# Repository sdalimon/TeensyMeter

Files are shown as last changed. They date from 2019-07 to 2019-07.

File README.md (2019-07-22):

# TeensyMeter
A simple voltmeter using a Teensy 3.5/3.6

This was a PCB I made up to experiment with software RMS calculation.

The hardware provides the following:
  - Socket for a Teensy 3.5 or Teensy 3.6 processor board
  - Socket for a SparkFun 7 segment display module (I2C connection only)
  - 4 pushbuttons
  - Differential Amplifier connected to input A9 of the Teensy
  
The input is differential, but not isolated.  The input range is +/- 60 V.  No protection against overvoltage is provided except the series resistors.  Do not connect to hazardous voltages.

The software constantly displays either the average (DC, positive only) voltage or the calculated voltage.  SW1 selects DC and SW2 selects RMS.

Calibration of offset and gain is supported, but the results are pretty good with 0.1% resistors even without calibration.  The calibration constants are stored in the EEPROM and sane defaults are used if the EEPROM is corrupt.  
To calibrate:
  - Connect 0.00 V to the input (short the wires)
  - Press SW3
  - Connect 10.00 V DC to the input
  - Press SW4
  
The hardware was designed in KiCAD 5.1.2.  The deisgn includes both 2 layer and 4 layer layouts.  Only the 2 layer layout is tested.

The software was written using the Arduino SDK with the TeensyDuino add-on.  THe followinjg libraries are used:  Wire, EEPROM, CRC32.

Known issues:
 - The resistor footprints are too small.
 - The UART interface of the 7 segment display would be easier to use.
 - The software should make it harder to accidentally calibrate.

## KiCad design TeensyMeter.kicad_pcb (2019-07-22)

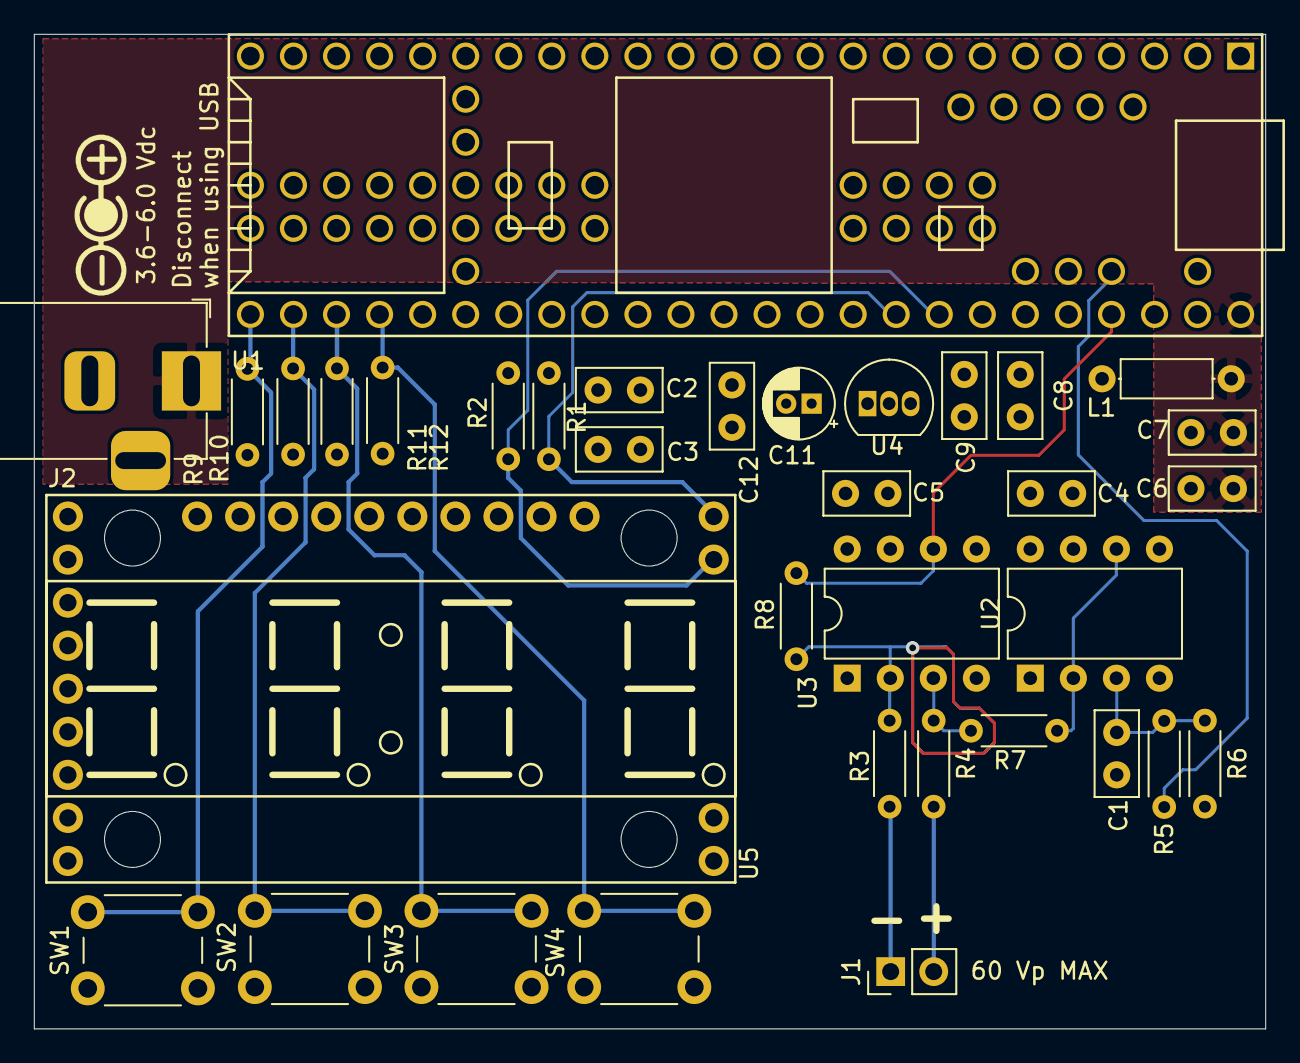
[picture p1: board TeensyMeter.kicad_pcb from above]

Board: 4 copper layers, 72.6 x 58.7 mm, 35 parts (0 on the bottom side), 20 nets.

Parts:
C1, C3, C4, C5, C7, C9, C12: 100n; C_Disc_D5.0mm_W2.5mm_P2.50mm
C2, C6, C8: 1u; C_Disc_D5.0mm_W2.5mm_P2.50mm
C11: 3u3; CP_Radial_D4.0mm_P1.50mm
J1: Conn_01x02; PinHeader_1x02_P2.54mm_Vertical
J2: Barrel_Jack; BarrelJack_Horizontal
L1: 600; L_Axial_L5.3mm_D2.2mm_P7.62mm_Horizontal_Vishay_IM-1
R1, R2, R5, R6, R9, R10, R11, R12: 10k; R_Axial_DIN0204_L3.6mm_D1.6mm_P5.08mm_Horizontal
R3, R4: 10MEG; R_Axial_DIN0204_L3.6mm_D1.6mm_P5.08mm_Horizontal
R7, R8: 221k; R_Axial_DIN0204_L3.6mm_D1.6mm_P5.08mm_Horizontal
SW1, SW2, SW3, SW4: SW_Push; SW_PUSH_6mm_H4.3mm
U1: Teensy3.6; Teensy35_36
U2, U3: MCP6281RT-E_OT DIP; DIP-8_W7.62mm
U4: LP2950-3.3_TO92; TO-92_Inline
U5: SparkFun_7seg

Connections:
+3.3VA: C4.1, C5.1, C11.1, C12.1, U2.7, U3.7, U4.1
+3V3: C2.1, C3.1, R1.1, R2.1, R9.1, R10.1, R11.1, R12.1, U1.15, U1.26, U1.51, U1.75, U5.6, U5.9, U5.10, U5.20
+5V: C6.1, C7.1, J2.1, L1.2, U1.53
+5VA: C8.1, C9.1, L1.1, U4.3
/A9: R8.1, U1.50, U3.6
/AREF: R5.1, U1.55
/INN: J1.1, R3.2
/INP: J1.2, R4.2
/MID: R7.2, U2.2, U2.6
/SCL: R2.2, U1.46, U5.12
/SDA: R1.2, U1.45, U5.13
GND: C2.2, C3.2, C6.2, C7.2, J2.2, SW1.1, SW2.1, SW3.1, SW4.1, U1.1, U1.27, U1.39, U1.61, U1.62, U1.74, U5.7, U5.8, U5.11, U5.21
GNDA: C1.2, C4.2, C5.2, C8.2, C9.2, C11.2, C12.2, R6.2, U1.52, U2.4, U3.4, U4.2
unnamed: C1.1, R5.2, R6.1, U2.3
unnamed: R3.1, R8.2, U3.2
unnamed: R4.1, R7.1, U3.3
unnamed: R9.2, SW1.2, U1.30
unnamed: R10.2, SW2.2, U1.31
unnamed: R11.2, SW3.2, U1.32
unnamed: R12.2, SW4.2, U1.33

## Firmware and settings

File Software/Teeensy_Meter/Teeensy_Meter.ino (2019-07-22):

#include <CRC32.h>

#include <Wire.h>
#include <EEPROM.h>

// Library Support Stuff
IntervalTimer t;   // Sampling timer

// Data Types
enum Mode {MODE_AVG, MODE_RMS, MODE_CAL};
struct CfgData {
  double gn;  // Calibrated Gain
  double ofs; // Calibrated Offset
  enum Mode mode; // Current Mode
  long crc;
};

// Strings
const char* STR_MODE_AVG = " DC "; // AVG with characters available on 7 seg display
const char* STR_MODE_RMS = "RMS "; // RMS with characters available on 7 seg display
const char* STR_MODE_CAL00 = "CL00"; // CAL 0.000 V - Prompt to apply 0 V for offset calibration
const char* STR_MODE_CAL10 = "CL10"; // CAL 10.00 V - Prompt to apply 10 V for gain calibration
const char CHR_7SEG_CLR = 0x76;  // Clear command for Sparkfun display
const char CHR_7SEG_DP = 0x77; // Followed by {X X AP CL D3 D2 D1 D0}

// Hardware configuration
const int led_pin = 13;
const int adc_in_pin = A9;               // ADC Input from amplifier
const int button_dc_pin = 33;              // Pushbuttons (0==Button pressed)
const int button_rms_pin = 34;
const int button_zero_pin = 35;
const int button_cal_pin = 36;
const int disp_i2c_addr = 0x71;          // SparkFun 7 seg ment display i2c address

// Parameters
const double default_gn = 3.3 / 65535 * 1000 / 20; // Default Gain
const int default_ofs = 32768;                  // Default Offset
const double cal_voltage = 10.0;                // Voltage to use for calibrating gain
const enum Mode default_mode = MODE_AVG;        // Start in Average (DC) mode

const long sample_rate = 1000; // 1 kHz sample rate
const long samples     = sample_rate * (10.0 / 50.0); // 10 cycles of 50 Hz

// EEPROM info for cal. storage
// 0 - 3 - Offset (double)
// 4 - 7 - Gain   (double)
// 8 - 11- CRC    (uint32_t)
const int eeprom_ofs_addr = 0;
const int eeprom_gn_addr = eeprom_ofs_addr + sizeof(double);
const int eeprom_crc_addr = eeprom_gn_addr + sizeof(double);

// Global Data
// Data Buffer
volatile uint16_t buff[samples];
struct CfgData cfg = {default_gn, default_ofs, MODE_AVG};

// Config_ADC - Set up the ADC
// Hits the ADC H/W registers directly to do some setup (Teensy 3.6 Specific)
// Enables the built in averaging function to get 32 smaple averaging
// Runs the calibration procedure described in teh manual (39.5.6)
void configADC(void)
{
  // 16 bit resolution
  analogReadResolution(16);

  // Set ADC for 32 sample average
  ADC0_SC3 |= 0x00000007;  // Set ADC to 32 averages mode
  ADC1_SC3 |= 0x00000007;  // Set ADC to 32 averages mode

  // Calibrate the ADC based on Ref Manual 39.5.6.
  ADC0_SC3 |= 0x00000080;
  while (ADC0_SC3 & 0x00000080); // Wait for cal to finish
  if ((ADC0_SC3 & 0x00000040) == 0) { // Cal sucess
    int i;
    i = (ADC0_CLP0 + ADC0_CLP1 + ADC0_CLP2 + ADC0_CLP3 + ADC0_CLP4 + ADC0_CLPS);
    i = i / 2;
    i = i | 0x00008000;
    ADC0_PG = i & 0x0000ffff;
    i = (ADC0_CLM0 + ADC0_CLM1 + ADC0_CLM2 + ADC0_CLM3 + ADC0_CLM4 + ADC0_CLMS);
    i = i / 2;
    i = i | 0x00008000;
    ADC0_MG = i & 0x0000ffff;
  }
  ADC1_SC3 |= 0x00000080;
  while (ADC1_SC3 & 0x00000080); // Wait for cal to finish
  if ((ADC1_SC3 & 0x00000040) == 0) { // Cal sucess
    int i;
    i = (ADC1_CLP0 + ADC1_CLP1 + ADC1_CLP2 + ADC1_CLP3 + ADC1_CLP4 + ADC1_CLPS);
    i = i / 2;
    i = i | 0x00008000;
    ADC1_PG = i & 0x0000ffff;
    i = (ADC1_CLM0 + ADC1_CLM1 + ADC1_CLM2 + ADC1_CLM3 + ADC1_CLM4 + ADC1_CLMS);
    i = i / 2;
    i = i | 0x00008000;
    ADC1_MG = i & 0x0000ffff;
  }
}

// get a sample and store it in the buffer
// Call at the sample rate (For example with
void getSample(void) {
  static int buf_ptr = 0;
  long val;

  val = analogRead(A9);
  noInterrupts();
  buff[buf_ptr] = val;
  interrupts();
  buf_ptr = (buf_ptr + 1) % samples;
}

// adcToV - Convert an ADC reading to Volts including offset and gain compensation
double adcToV(int a) {
  return (a - cfg.ofs) * cfg.gn;
}

// calcAvg - Calculate the average value of the buffer
double calcAvg(void) {
  double avg = 0;
  for (int i = 0; i < samples; i++) {
    avg += adcToV(buff[i]);
  }
  avg /= samples;
  return avg;
}

// calcRms - Calculate the RMS value of the buffer
double calcRms(void) {
  double avg = 0;
  for (int i = 0; i < samples; i++) {
    avg += pow(adcToV(buff[i]), 2);
  }
  avg /= samples;
  avg = sqrt(avg);
  return avg;
}

//dumpBuf - print the current buffer contents
void dumpBuf(void) {
  for (int i = 0; i < samples; i++) {
    Serial.println(buff[i]);
  }
  Serial.println();
}

// Convert a double between 0 and 99.99 to a string to send to the Sparkfun display including Clear and Decimal control
void printDoubleTo7seg(double x) {
  char buf[10];
  int i;
  buf[0] = 0x76; // Clear Display
  buf[1] = 0x77; // Decimal Control
  buf[2] = 0x02; // Just middle decimal
  //Serial.println(x);
  if (x < 0 || x > 99.99) {
    buf[3] = 0;
    return;
  }
  //Serial.print(x);Serial.println('\t');
  i = x / 10;
  buf[3] = '0' + i;
  x -= i * 10;
  //Serial.print(i);Serial.print('\t');Serial.println(x);
  i = x / 1;
  buf[4] = '0' + i;
  x -= i * 1;
  //Serial.print(i);Serial.print('\t');Serial.println(x);
  i = x / 0.1;
  buf[5] = '0' + i;
  x -= i * 0.1;
  //Serial.print(i);Serial.print('\t');Serial.println(x);
  i = x / 0.01;
  buf[6] = '0' + i;
  ; x -= i * 0.01;
  buf[7] = 0;
  //for (i = 0; i < 8; i++) {
  //  Serial.print(buf[i], HEX);
  //  Serial.print(' ');
  //}
  //Serial.println();
  //Serial.print("I2C Tx");
  Wire.beginTransmission(disp_i2c_addr);
  Wire.write(buf);
  Wire.endTransmission();
  //Serial.println(".");
}

// rawCalcAvg - Calculate the average value of the buffer in ADC counts for calibration
double rawCalcAvg(void) {
  double avg = 0;
  for (int i = 0; i < samples; i++) {
    avg += buff[i];
  }
  avg /= samples;
  return avg;
}

// Determines the offset and updates the offset value
// Short the inputs before running
void cal_zero(void) {
  delay(200);
  cfg.ofs = rawCalcAvg();
  Serial.print("New Ofs: "); Serial.println(cfg.ofs, 6);
  EEPROM.put(eeprom_ofs_addr, cfg.ofs);
  updateEepromCrc();
}

// Determines the system gain and updates the gain value
// Run cal_zero() first
// Apply 10.0 V DC to the input before running
void cal_10v(void) {
  delay(200);
  cfg.gn = cal_voltage / (rawCalcAvg() - cfg.ofs);
  Serial.print("New Gain: "); Serial.println(cfg.gn, 6);
  EEPROM.put(eeprom_gn_addr, cfg.gn);
  updateEepromCrc();
}

// Check CRC of EEPROM
int checkEepromCrc() {
  CRC32 crc;
  int i;
  uint32_t stored_crc;
  uint32_t calc_crc;

  // Retrieve CRC stored in EEPROM
  EEPROM.get(eeprom_crc_addr, stored_crc);

  // Calculate CRC of rest of EEPROM
  for(i=0;i<eeprom_crc_addr;i++) {
    crc.update(EEPROM.read(i));
  }
  calc_crc = crc.finalize();
  
  Serial.print("EEPROM Stored CRC: ");
  Serial.println(stored_crc, HEX);
  Serial.print("EEPROM Calc CRC:   ");
  Serial.println(calc_crc, HEX);
  return calc_crc==stored_crc;
}

// Set CRC of EEPROM
// Update data first...
void updateEepromCrc() {
  CRC32 crc;
  int i;
  uint32_t calc_crc;

  // Calculate CRC of EEPROM
  for(i=0;i<eeprom_crc_addr;i++) {
    crc.update(EEPROM.read(i));
  }
  calc_crc = crc.finalize();

  EEPROM.put (eeprom_crc_addr, calc_crc);
  
  Serial.print("Update EEPROM CRC:   ");
  Serial.println(calc_crc, HEX);
}


// Initial Setup
void setup() {
  // Serial Port Setup
  Serial.begin(115200);
  delay(1000);
  //while (!Serial) {
  //  ;
  //}

  // Print Banner
  Serial.println("Teensy Meter");
  Serial.print("Samples: "); Serial.println(samples);
  Serial.print("Sample Rate: "); Serial.print(sample_rate); Serial.println(" kHz");

  // Set up buttons
  // Use INPUT_PULLUP if you don't have external pullups
  Serial.print("Setting up buttons");
  pinMode(button_dc_pin, INPUT);
  pinMode(button_rms_pin, INPUT);
  pinMode(button_zero_pin, INPUT);
  pinMode(button_cal_pin, INPUT);
  Serial.println('.');

  // Set up the ADC
  Serial.print("Calibrating ADC");
  configADC();
  Serial.println('.');

  // Display calibration constants
  Serial.println("Calibration Constants:");
  if(checkEepromCrc()) {
    Serial.println("EEPROM Good - Using EEPROM values");
    EEPROM.get(eeprom_ofs_addr, cfg.ofs);
    EEPROM.get(eeprom_gn_addr, cfg.gn);
  } else {
    Serial.println("EEPROM Bad - Using Default values");
    cfg.ofs = default_ofs;
    cfg.gn  = default_gn;
  }  
  Serial.print("Offset: "); Serial.println(cfg.ofs, 6);
  Serial.print("Gain: "); Serial.println(cfg.gn, 6);

  // Start automatic sampling
  Serial.print("Starting sampling");
  t.begin(getSample, 1000000 / sample_rate); // Sample rate is in us
  Serial.println('.');

  // Start I2C Driver
  Serial.print("Starting I2C");
  Wire.begin();
  Serial.println('.');

  // Done setup
  Serial.println("Running...");
}

void loop() {
  double x;

  // Only update display every 200ms
  delay(200);

  // Handle button presses - no debounce
  if (digitalRead(button_dc_pin) == LOW) cfg.mode = MODE_AVG;
  if (digitalRead(button_rms_pin) == LOW) cfg.mode = MODE_RMS;
  if (digitalRead(button_zero_pin) == LOW) cal_zero();
  if (digitalRead(button_cal_pin) == LOW) cal_10v();

  //  dumpBuf();
  //  return;
  switch (cfg.mode) {
    case MODE_AVG:
      x = calcAvg();
      break;
    case MODE_RMS:
      x = calcRms();
      break;
    default:
      cfg.mode = MODE_AVG;
      x = -1.0;
  }
  printDoubleTo7seg(x);
  //if(cfg.mode == MODE_AVG) Serial.print("DC:  ");
  //if(cfg.mode == MODE_RMS) Serial.print("RMS: ");
  //Serial.println(x,6);
}
